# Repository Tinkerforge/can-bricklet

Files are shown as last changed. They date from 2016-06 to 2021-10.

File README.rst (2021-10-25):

CAN Bricklet
============

This repository contains the firmware source code and the hardware design
files. The documentation generator configs can be found at
https://github.com/Tinkerforge/generators

Repository Content
------------------

software/:
 * examples/: Examples for all supported languages
 * build/: Compiled files
 * src/: Source code of firmware
 * Makefile: Makefile to build project

hardware/:
 * Contains KiCad project files and additionally schematics as PDF

datasheets/:
 * Contains datasheets for sensors and complex ICs that are used

Hardware
--------

The hardware is designed with the open source EDA Suite KiCad
(http://www.kicad.org). Before you are able to open the files,
you have to install the Tinkerforge kicad-libraries
(https://github.com/Tinkerforge/kicad-libraries). You can either clone
them directly in hardware/ or clone them in a separate folder and
symlink them into hardware/
(ln -s kicad_path/kicad-libraries project_path/hardware). After that you
can open the .pro file in hardware/ with KiCad and from there view and
modify the schematics and the PCB layout.

Software
--------

If you want to do your own Brick/Bricklet firmware development we highly
recommend that you use our build environment setup script and read the
tutorial (https://www.tinkerforge.com/en/doc/Tutorials/Tutorial_Build_Environment/Tutorial.html).

To compile the C code we recommend you to install the newest GNU Arm Embedded
Toolchain (https://launchpad.net/gcc-arm-embedded/+download).
You also need to install bricklib (https://github.com/Tinkerforge/bricklib)
and brickletlib (https://github.com/Tinkerforge/brickletlib).

You can either clone it directly in software/src/ or clone it in a
separate folder and symlink it into software/src/
(ln -s bricklib_path/bricklib project_path/software/src/ and
ln -s brickletlib_path/brickletlib project_path/software/src/).
Finally make sure to have CMake installed
(http://www.cmake.org/cmake/resources/software.html).

After that you can build the firmware by invoking make in software/.
The firmware (.bin) can then be found in software/build/ and uploaded
with brickv (click button "Flashing" on start screen).

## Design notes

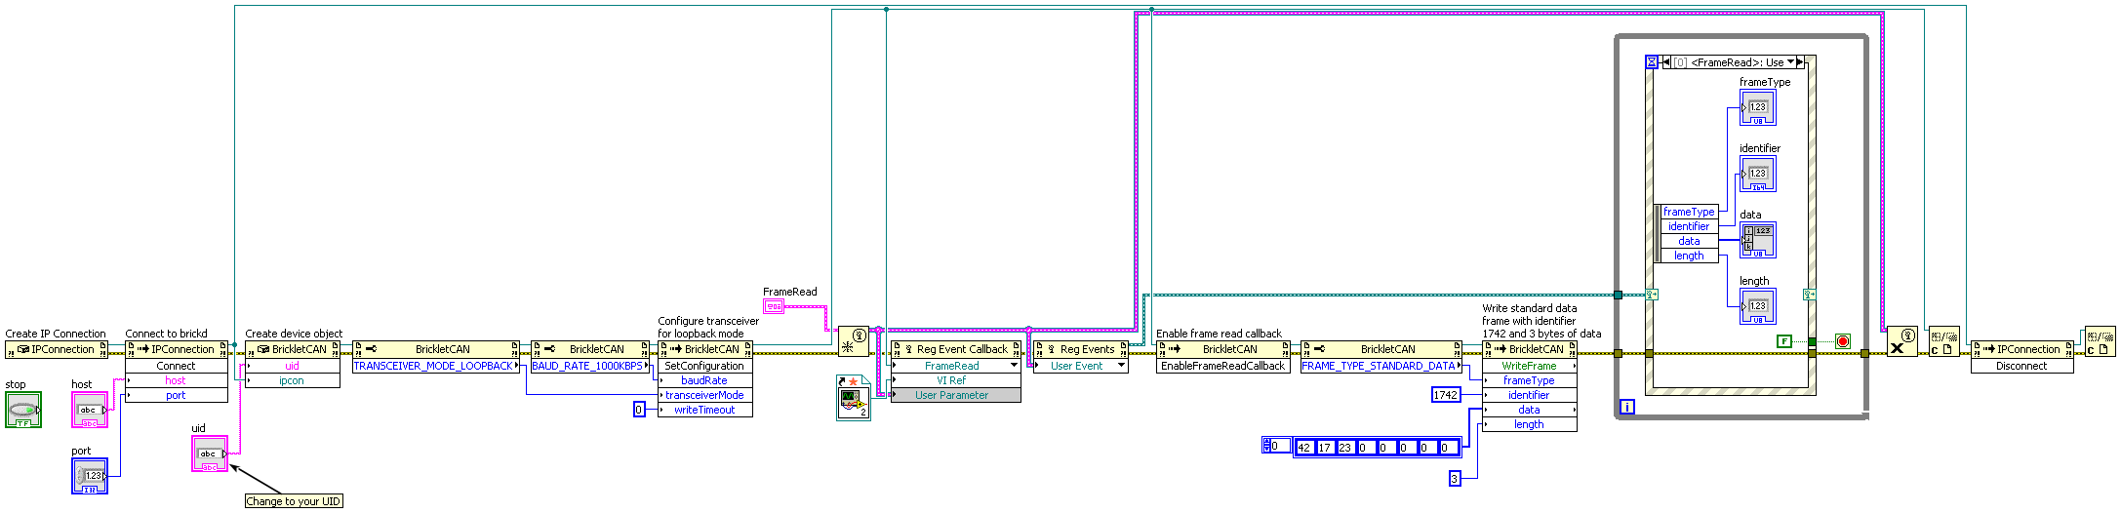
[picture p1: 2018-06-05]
software/examples/labview/Example Loopback.vi.png

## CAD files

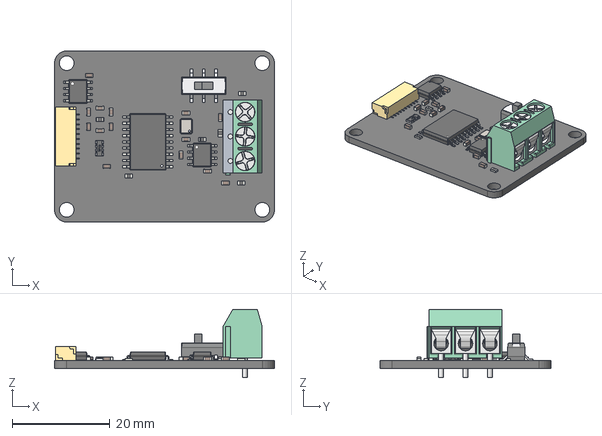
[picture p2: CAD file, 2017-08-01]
hardware/can.step
45.0 x 35.0 x 14.0 mm

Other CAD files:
hardware/can.FCStd

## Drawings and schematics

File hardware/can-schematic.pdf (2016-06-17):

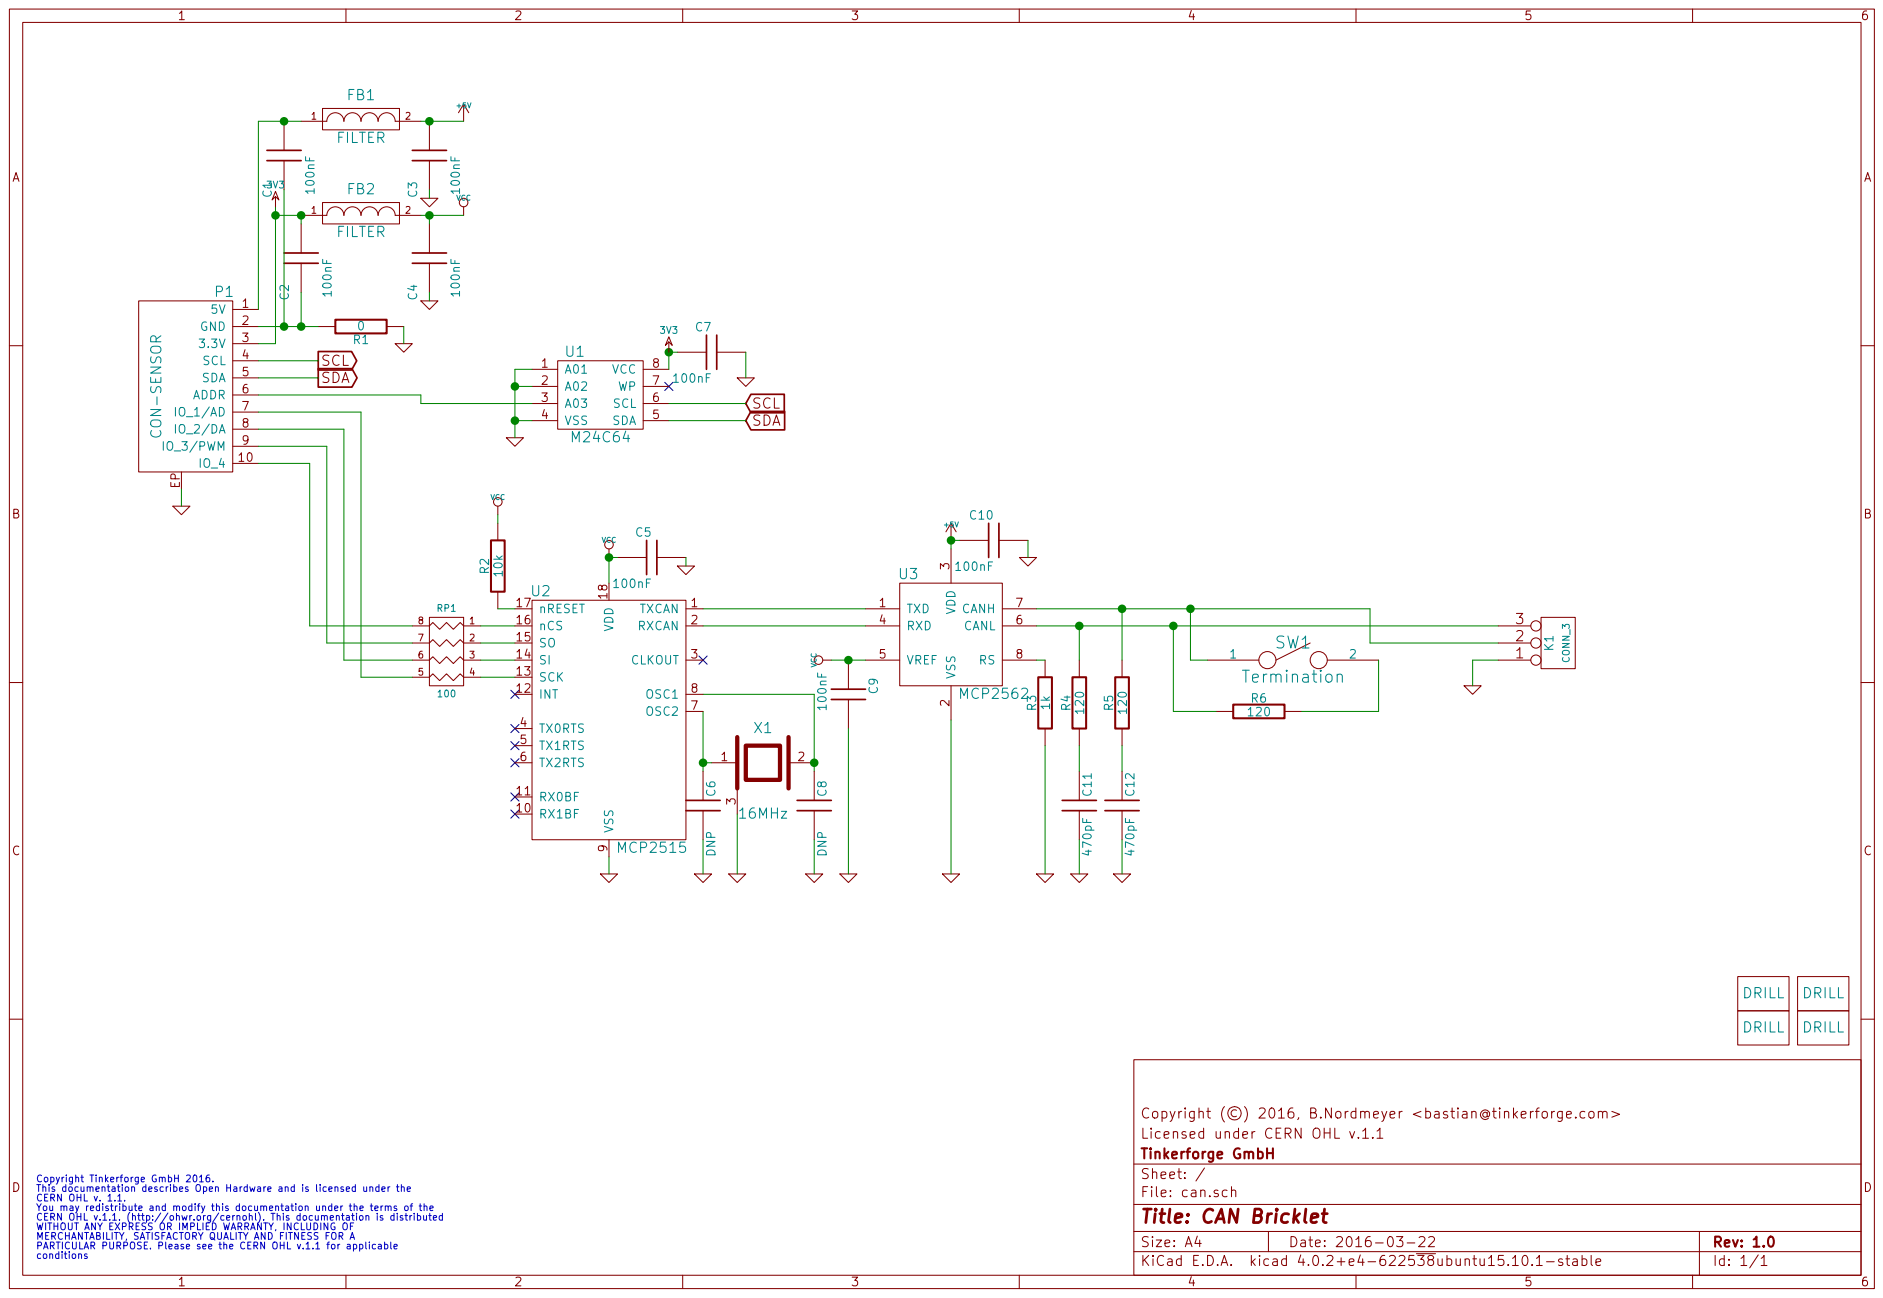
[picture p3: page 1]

3 RXD 4 VREF 5 CANL 6 CANH 7 RS 8 U3 MCP2562

Licensed under CERN OHL v.1.1 Copyright (©) 2016, B.Nordmeyer <bastian@tinkerforge.com>

Id: 1/1 Title: CAN Bricklet File: can.sch Sheet: / Tinkerforge GmbH

Copyright Tinkerforge GmbH 2016. This documentation describes Open Hardware and is licensed under the CERN OHL v. 1.1. You may redistribute and modify this documentation under the terms of the CERN OHL v.1.1. (http://ohwr.org/cernohl). This documentation is distributed WITHOUT ANY EXPRESS OR IMPLIED WARRANTY, INCLUDING OF MERCHANTABILITY, SATISFACTORY QUALITY AND FITNESS FOR A

PARTICULAR PURPOSE. Please see the CERN OHL v.1.1 for applicable

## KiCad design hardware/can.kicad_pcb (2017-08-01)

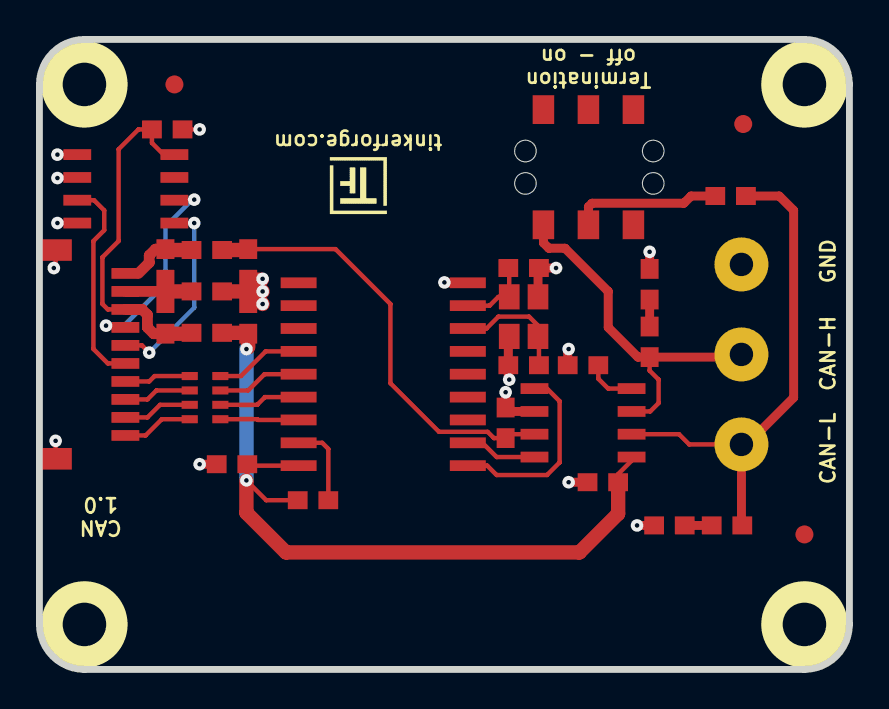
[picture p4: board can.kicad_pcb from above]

Board: 2 copper layers, 45.0 x 35.0 mm, 37 parts (0 on the bottom side), 28 nets.

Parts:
C1, C2, C3, C4, C5, C7, C9, C10: 100nF; C0603E
C6, C8: DNP; C0603E
C11, C12: 470pF; C0603E
FB1, FB2: FILTER; C0603E
Fiducial_Mark: VAL**; Fiducial_Mark
Fiducial_Mark#2, Fiducial_Mark#3: VAL**; Fiducial_Mark
K1: CONN_3; AKL_5_3
P1: CON-SENSOR
R1: 0; R0603E
R2: 10k; R0603E
R3: 1k; R0603E
R4, R5, R6: 120; R0603E
RP1: 100; 0603X4
SW1: Termination; SLIDE_SWITCH
U1: M24C64; SOIC8
U2: MCP2515; SOIC-18
U3: MCP2562; SOIC8
U4, U5, U6, U7: DRILL; DRILL_NP
VAL: WEEE_7mm
VAL#2: CE_5mm
X1: 16MHz; CRYSTAL_3225

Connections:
3V3: C2.2, C7.1, FB2.1, P1.3, U1.8
+5V: C3.2, C10.1, FB1.2, U3.3
GND: C3.1, C4.1, C5.2, C6.2, C7.2, C8.2, C9.2, C10.2, C11.2, C12.2, K1.1, P1.EP, R1.1, R3.1, U1.1, U1.2, U1.4, U2.9, U3.2, X1.3
unnamed: C1.1, C2.1, P1.2, R1.2
unnamed: C1.2, FB1.1, P1.1
unnamed: C6.1, U2.7, X1.1
unnamed: C8.1, U2.8, X1.2
unnamed: C11.1, R4.1
unnamed: C12.1, R5.1
unnamed: K1.2, R5.2, SW1.1, U3.7
unnamed: K1.3, R4.2, R6.1, U3.6
unnamed: P1.6, U1.3
unnamed: P1.7, RP1.5
unnamed: P1.8, RP1.6
unnamed: P1.9, RP1.7
unnamed: P1.10, RP1.8
unnamed: R2.1, U2.17
unnamed: R3.2, U3.8
unnamed: R6.2, SW1.2
unnamed: RP1.1, U2.16
unnamed: RP1.2, U2.15
unnamed: RP1.3, U2.14
unnamed: RP1.4, U2.13
unnamed: U2.1, U3.1
unnamed: U2.2, U3.4
SCL: P1.4, U1.6
SDA: P1.5, U1.5
VCC: C4.2, C5.1, C9.1, FB2.2, R2.2, U2.18, U3.5

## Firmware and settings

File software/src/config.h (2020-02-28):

/* can-bricklet
 * Copyright (C) 2016 Matthias Bolte <matthias@tinkerforge.com>
 *
 * config.h: CAN Bricklet specific configuration
 *
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
 * You should have received a copy of the GNU Lesser General Public
 * License along with this library; if not, write to the
 * Free Software Foundation, Inc., 59 Temple Place - Suite 330,
 * Boston, MA 02111-1307, USA.
 */

#ifndef CONFIG_H
#define CONFIG_H

#include <stdint.h>
#include <stdbool.h>

#include "bricklib/drivers/board/sam3s/SAM3S.h"
#include "bricklib/drivers/pio/pio.h"

#include "can.h"

#define BOARD_MCK 64000000

#define BRICKLET_FIRMWARE_VERSION_MAJOR 2
#define BRICKLET_FIRMWARE_VERSION_MINOR 0
#define BRICKLET_FIRMWARE_VERSION_REVISION 1

#define BRICKLET_HARDWARE_VERSION_MAJOR 1
#define BRICKLET_HARDWARE_VERSION_MINOR 0
#define BRICKLET_HARDWARE_VERSION_REVISION 0

#define BRICKLET_DEVICE_IDENTIFIER 270

#define SPI_CLK (BS->pin1_ad)
#define SPI_SDI (BS->pin2_da)
#define SPI_SDO (BS->pin3_pwm)
#define SPI_CS  (BS->pin4_io)

#define LOGGING_LEVEL LOGGING_DEBUG
#define DEBUG_BRICKLET 0

#define INVOCATION_IN_BRICKLET_CODE

#define INST_RESET                             0b11000000
#define INST_READ                              0b00000011
#define INST_READ_RX_BUFFER_RXB0SIDH           0b10010000
#define INST_READ_RX_BUFFER_RXB0D0             0b10010010
#define INST_READ_RX_BUFFER_RXB1SIDH           0b10010100
#define INST_READ_RX_BUFFER_RXB1D0             0b10010110
#define INST_WRITE                             0b00000010
#define INST_WRITE_TX_BUFFER_TXB0SIDH          0b01000000
#define INST_WRITE_TX_BUFFER_TXB0D0            0b01000001
#define INST_WRITE_TX_BUFFER_TXB1SIDH          0b01000010
#define INST_WRITE_TX_BUFFER_TXB1D0            0b01000011
#define INST_WRITE_TX_BUFFER_TXB2SIDH          0b01000100
#define INST_WRITE_TX_BUFFER_TXB2D0            0b01000101
#define INST_RTS_TXB0                          0b10000001
#define INST_RTS_TXB1                          0b10000010
#define INST_RTS_TXB2                          0b10000100
#define INST_READ_STATUS                       0b10100000
#define INST_READ_RX_STATUS                    0b10110000
#define INST_WRITE_BITS                        0b00000101

#define INST_READ_STATUS_CANINTF_TX2IF         0b10000000
#define INST_READ_STATUS_TXB2CTRL_TXREQ        0b01000000
#define INST_READ_STATUS_CANINTF_TX1IF         0b00100000
#define INST_READ_STATUS_TXB1CTRL_TXREQ        0b00010000
#define INST_READ_STATUS_CANINTF_TX0IF         0b00001000
#define INST_READ_STATUS_TXB0CTRL_TXREQ        0b00000100
#define INST_READ_STATUS_CANINTF_RX1IF         0b00000010
#define INST_READ_STATUS_CANINTF_RX0IF         0b00000001

#define REG_BFPCTRL                            0x0C
#define REG_TXRTSCTRL                          0x0D
#define REG_CANSTAT                            0x0E
#define REG_CANCTRL                            0x0F
#define REG_TEC                                0x1C
#define REG_REC                                0x1D
#define REG_CNF3                               0x28
#define REG_CNF2                               0x29
#define REG_CNF1                               0x2A
#define REG_CANINTE                            0x2B
#define REG_CANINTF                            0x2C
#define REG_EFLG                               0x2D

#define REG_RXF0SIDH                           0x00
#define REG_RXF0SIDL                           0x01
#define REG_RXF0EID8                           0x02
#define REG_RXF0EID0                           0x03

#define REG_RXF1SIDH                           0x04
#define REG_RXF1SIDL                           0x05
#define REG_RXF1EID8                           0x06
#define REG_RXF1EID0                           0x07

#define REG_RXF2SIDH                           0x08
#define REG_RXF2SIDL                           0x09
#define REG_RXF2EID8                           0x0A
#define REG_RXF2EID0                           0x0B

#define REG_RXF3SIDH                           0x10
#define REG_RXF3SIDL                           0x11
#define REG_RXF3EID8                           0x12
#define REG_RXF3EID0                           0x13

#define REG_RXF4SIDH                           0x14
#define REG_RXF4SIDL                           0x15
#define REG_RXF4EID8                           0x16
#define REG_RXF4EID0                           0x17

#define REG_RXF5SIDH                           0x18
#define REG_RXF5SIDL                           0x19
#define REG_RXF5EID8                           0x1A
#define REG_RXF5EID0                           0x1B

#define REG_RXM0SIDH                           0x20
#define REG_RXM0SIDL                           0x21
#define REG_RXM0EID8                           0x22
#define REG_RXM0EID0                           0x23

#define REG_RXM1SIDH                           0x24
#define REG_RXM1SIDL                           0x25
#define REG_RXM1EID8                           0x26
#define REG_RXM1EID0                           0x27
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

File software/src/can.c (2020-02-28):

/* can-bricklet
 * Copyright (C) 2016 Matthias Bolte <matthias@tinkerforge.com>
 *
 * can.c: Implementation of CAN Bricklet messages
 *
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
 * You should have received a copy of the GNU Lesser General Public
 * License along with this library; if not, write to the
 * Free Software Foundation, Inc., 59 Temple Place - Suite 330,
 * Boston, MA 02111-1307, USA.
 */

#include "can.h"

#include "brickletlib/bricklet_entry.h"
#include "bricklib/bricklet/bricklet_communication.h"
#include "bricklib/utility/util_definitions.h"
#include "config.h"

// Definitions:
// F_OSC = 16MHz
// Baud Rate Prescaler (BRP) = [0..63]
// PRSEG = [0..7]
// PHSEG1 = [0..7]
// PHSEG2 = [0..7]
// Time Quanta (T_Q) = 2 * (BRP + 1) / F_OSC
// FixedSyncSeg = 1 * T_Q
// PropSeg = (PRSEG + 1) * T_Q
// PS1 = (PHSEG1 + 1) * T_Q
// PS2 = (PHSEG2 + 1) * T_Q
// Nominal Bit Time (NBT) = FixedSyncSeg + PropSeg + PS1 + PS2
//
// Rules:
// PropSeg + PS1 >= PS2
// PropSeg + PS1 >= T_DELAY
// PS2 > SJW
//
// Recommendation:
// Synchronization Jump Width = 1 * T_Q -> SJW = 1
// SamplingPoint = 60% to 70% of NBT
//
// Typical:
// T_DELAY = 1 * T_Q to 2 * T_Q

// FIXME: CANopen specification 301 recommends to put the SamplingPoint at 87.5%
const uint8_t baud_rate_cnf[][3] = { // CNF3, CNF2, CNF1
	// BAUD_RATE_10000 (NBT = 100µs): BRP = 49 -> T_Q = 6.25µs -> NBT = 16 * T_Q,
	// PRSEG = 1 -> PropSeg = 2 * T_Q, PHSEG1 = 6 -> PS1 = 7 * T_Q, PHSEG2 = 5 -> PS2 = 6 * T_Q, SamplingPoint = 62.5%
	{ 5 << REG_CNF3_PHSEG2_offset,
	  REG_CNF2_BTLMODE | (6 << REG_CNF2_PHSEG1_offset) | (1 << REG_CNF2_PRSEG_offset),
	  49 << REG_CNF1_BRP_offset },

	// BAUD_RATE_20000 (NBT = 50µs): BRP = 24 -> T_Q = 3.125µs -> NBT = 16 * T_Q,
	// PRSEG = 1 -> PropSeg = 2 * T_Q, PHSEG1 = 6 -> PS1 = 7 * T_Q, PHSEG2 = 5 -> PS2 = 6 * T_Q, SamplingPoint = 62.5%
	{ 5 << REG_CNF3_PHSEG2_offset,
	  REG_CNF2_BTLMODE | (6 << REG_CNF2_PHSEG1_offset) | (1 << REG_CNF2_PRSEG_offset),
	  24 << REG_CNF1_BRP_offset },

	// BAUD_RATE_50000 (NBT = 20µs): BRP = 9 -> T_Q = 1.25µs -> NBT = 16 * T_Q,
	// PRSEG = 1 -> PropSeg = 2 * T_Q, PHSEG1 = 6 -> PS1 = 7 * T_Q, PHSEG2 = 5 -> PS2 = 6 * T_Q, SamplingPoint = 62.5%
	{ 5 << REG_CNF3_PHSEG2_offset,
	  REG_CNF2_BTLMODE | (6 << REG_CNF2_PHSEG1_offset) | (1 << REG_CNF2_PRSEG_offset),
	  9 << REG_CNF1_BRP_offset },

	// BAUD_RATE_125000 (NBT = 8µs): BRP = 3 -> T_Q = 0.5µs -> NBT = 16 * T_Q,
	// PRSEG = 1 -> PropSeg = 2 * T_Q, PHSEG1 = 6 -> PS1 = 7 * T_Q, PHSEG2 = 5 -> PS2 = 6 * T_Q, SamplingPoint = 62.5%
	{ 5 << REG_CNF3_PHSEG2_offset,
	  REG_CNF2_BTLMODE | (6 << REG_CNF2_PHSEG1_offset) | (1 << REG_CNF2_PRSEG_offset),
	  3 << REG_CNF1_BRP_offset },

	// BAUD_RATE_250000 (NBT = 4µs): BRP = 1 -> T_Q = 0.25µs -> NBT = 16 * T_Q,
	// PRSEG = 1 -> PropSeg = 2 * T_Q, PHSEG1 = 6 -> PS1 = 7 * T_Q, PHSEG2 = 5 -> PS2 = 6 * T_Q, SamplingPoint = 62.5%
	{ 5 << REG_CNF3_PHSEG2_offset,
	  REG_CNF2_BTLMODE | (6 << REG_CNF2_PHSEG1_offset) | (1 << REG_CNF2_PRSEG_offset),
	  1 << REG_CNF1_BRP_offset },

	// BAUD_RATE_500000 (NBT = 2µs): BRP = 0 -> T_Q = 0.125µs -> NBT = 16 * T_Q,
	// PRSEG = 1 -> PropSeg = 2 * T_Q, PHSEG1 = 6 -> PS1 = 7 * T_Q, PHSEG2 = 5 -> PS2 = 6 * T_Q, SamplingPoint = 62.5%
	{ 5 << REG_CNF3_PHSEG2_offset,
	  REG_CNF2_BTLMODE | (6 << REG_CNF2_PHSEG1_offset) | (1 << REG_CNF2_PRSEG_offset),
	  0 },

	// BAUD_RATE_800000 (NBT = 1.25µs): BRP = 0 -> T_Q = 0.125µs -> NBT = 10 * T_Q,
	// PRSEG = 0 -> PropSeg = 1 * T_Q, PHSEG1 = 3 -> PS1 = 4 * T_Q, PHSEG2 = 3 -> PS2 = 4 * T_Q, SamplingPoint = 60.0%
	{ 3 << REG_CNF3_PHSEG2_offset,
	  REG_CNF2_BTLMODE | (3 << REG_CNF2_PHSEG1_offset),
	  0 },

	// BAUD_RATE_1000000 (NBT = 1µs): BRP = 0 -> T_Q = 0.125µs -> NBT = 8 * T_Q,
	// PRSEG = 0 -> PropSeg = 1 * T_Q, PHSEG1 = 2 -> PS1 = 3 * T_Q, PHSEG2 = 2 -> PS2 = 3 * T_Q, SamplingPoint = 62.5%
	{ 2 << REG_CNF3_PHSEG2_offset,
	  REG_CNF2_BTLMODE | (2 << REG_CNF3_PHSEG2_offset),
	  0 }
};

const uint8_t transceiver_mode_canctrl[] = {
	REG_CANCTRL_REQOP_NORMAL, // TRANSCEIVER_MODE_NORMAL
	REG_CANCTRL_REQOP_LOOPBACK, // TRANSCEIVER_MODE_LOOPBACK
	REG_CANCTRL_REQOP_READ_ONLY, // TRANSCEIVER_MODE_READ_ONLY
};

void constructor(void) {
	_Static_assert(sizeof(BrickContext) <= BRICKLET_CONTEXT_MAX_SIZE,
	               "BrickContext too big");

	BrickContext *bc = BC;

	bc->status = 0;

	bc->txb_start = 0;
	bc->txb_end = 0;

	bc->rxb_start = 0;
	bc->rxb_end = 0;

	bc->write_timeout_count = 0;
	bc->read_register_overflow_count = 0;
	bc->read_buffer_overflow_count = 0;

	bc->baud_rate = BAUD_RATE_125000;
	bc->transceiver_mode = TRANSCEIVER_MODE_NORMAL;
	bc->write_timeout = 0;
	bc->write_timeout_counter = 0;

	bc->filter_mode = FILTER_MODE_ACCEPT_ALL;
	bc->filter_mask = 0;
	bc->filter1 = 0;
	bc->filter2 = 0;

	// Pins
	SPI_CS.type = PIO_OUTPUT_1;
	SPI_CS.attribute = PIO_DEFAULT;
	BA->PIO_Configure(&SPI_CS, 1);

	SPI_CLK.type = PIO_OUTPUT_1;
	SPI_CLK.attribute = PIO_DEFAULT;
	BA->PIO_Configure(&SPI_CLK, 1);

	SPI_SDI.type = PIO_OUTPUT_1;
	SPI_SDI.attribute = PIO_DEFAULT;
	BA->PIO_Configure(&SPI_SDI, 1);

	SPI_SDO.type = PIO_INPUT;
	SPI_SDO.attribute = PIO_DEFAULT;
	BA->PIO_Configure(&SPI_SDO, 1);

	SLEEP_MS(2);
	mcp2515_reset(); // Enters config mode
	SLEEP_US(200);

	apply_config();
}

void destructor(void) {
}

void invocation(const ComType com, const uint8_t *data) {
	switch (((StandardMessage*)data)->header.fid) {
		case FID_WRITE_FRAME:                               write_frame(com, (WriteFrame *)data); break;
		case FID_READ_FRAME:                                read_frame(com, (ReadFrame *)data); break;
		case FID_ENABLE_FRAME_READ_CALLBACK:                enable_frame_read_callback(com, (EnableFrameReadCallback*)data); break;
		case FID_DISABLE_FRAME_READ_CALLBACK:               disable_frame_read_callback(com, (DisableFrameReadCallback*)data); break;
		case FID_IS_FRAME_READ_CALLBACK_ENABLED:            is_frame_read_callback_enabled(com, (IsFrameReadCallbackEnabled*)data); break;
		case FID_SET_CONFIGURATION:                         set_configuration(com, (SetConfiguration *)data); break;
		case FID_GET_CONFIGURATION:                         get_configuration(com, (GetConfiguration *)data); break;
		case FID_SET_READ_FILTER:                           set_read_filter(com, (SetReadFilter *)data); break;
		case FID_GET_READ_FILTER:                           get_read_filter(com, (GetReadFilter *)data); break;
		case FID_GET_ERROR_LOG:                             get_error_log(com, (GetErrorLog *)data); break;
		case FID_SET_FRAME_READABLE_CALLBACK_CONFIGURATION: set_frame_readable_callback_configuration(com, (SetFrameReadableCallbackConfiguration*)data); break;
		case FID_GET_FRAME_READABLE_CALLBACK_CONFIGURATION: get_frame_readable_callback_configuration(com, (GetFrameReadableCallbackConfiguration*)data); break;
		default:                                            BA->com_return_error(data, sizeof(MessageHeader), MESSAGE_ERROR_CODE_NOT_SUPPORTED, com); break;
	}
}
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

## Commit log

2015-11-10 rs232 bricklet data copied, schematic adapted to CAN
    [can.kicad_pcb, can.sch]
2015-11-11 footprints for all symbols added
    [can.sch]
2015-11-11 fully routed
    [can.kicad_pcb, can.sch]
2015-11-17 fix discription
    [can.kicad_pcb]
2016-02-01 add pullup resistor for reset
    [can.sch]
2016-02-11 Add frame-read callback
2016-02-11 Optimize SPI communication in tick
    To make it fit better into the 200µs timeslice.
2016-02-12 Fix extended identifier reconstruction
    [can.c]
2016-02-12 Ignore data registers for received remote frames
2016-02-12 First read then write to avoid read register overflow in loopback mode
    [can.c]
2016-02-12 Avoid false-positive TXB0 header check
    This could happens if the first frame to be written is a standard data
    frame with identifier 0 and no data. In this case the TXB0 header would
    be all zero. In this case the header would not be written und result in
    sending an undefined frame, because the TXB0 registers are undefined
    after a reset.
    [can.c, config.h]
2016-02-12 Don't write unnecessary data bytes for remote frames
2016-02-15 Fix for loop condition
    [can.c]
2016-02-15 Fix value of unused register constant
    [config.h]
2016-02-15 Force extended identifer to be 0 when writing standard frames
    Also don't assume that the frame length is a 4 bit value.
2016-02-17 Add read filter and timeout handling
2016-03-04 remove serial connector
    [can.kicad_pcb, can.sch]
2016-03-22 more space between resistors and terminal
    [can.kicad_pcb]
2016-03-22 fix can-h/can-l labeling
    [can.kicad_pcb]
2016-03-22 adapt filter values
    [can.kicad_pcb, can.sch]
2016-06-17 add schematic
2017-08-01 Add 3d information (final)
    [can.kicad_pcb, can.sch]
2017-08-01 Add 3d model (*.step & *.FCStd)
    [can.FCStd, can.step]
2018-02-20 Cleanup KiCad libraries config
    Ensure LibDir=kicad-libraries and LibName1=tinkerforge.
    Remove special library.
2020-02-28 Add frame readable callback.
2020-02-28 Change frame readable ccf to new style.
2020-03-17 examples: Add constant translation for frame type
2021-10-25 Update KiCad link
    https://www.kicad.org/blog/2021/10/Avoid-links-to-former-kicad-domain/

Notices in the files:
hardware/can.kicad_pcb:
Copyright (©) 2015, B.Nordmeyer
